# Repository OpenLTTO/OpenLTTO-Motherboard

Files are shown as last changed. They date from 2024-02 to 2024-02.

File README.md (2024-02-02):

# OpenLTTO
The OpenLTTO Project is an attempt to recreate the Lazer Tag Team Ops protocol, and game system, in a completely open-source solution. Eventually our intent, is to expand on the LTTO system, adding new functionality, and features, while maintaining backwards compatibility with this classic Lazer Tag gear.

> This Project wouldn't be possible without all the hard work of Richie Mickan https://github.com/rmick
> His work on recreating the LTTO Protocol, and the development of the Combobulator app are core to the firmware and capabilities of this project.

> Additionally this is built on top of the excellent product developed and released by Hasbro/Tiger Electronics. And the work done by Tag Ferret to release the technical specs, and unlock much of the magic of the protocol, and the inner workings.

We intend to do this via a collection of open-source hardware components that can act as building blocks, to build anything you might require for a Lazer Tag game (Taggers, Hosting Pods, Zone controllers, utilities, etc). And an opensource firmware to operate it all. 

Shield: [][cc-by-nc-sa]

This work is licensed under a
[Creative Commons Attribution-NonCommercial-ShareAlike 4.0 International License][cc-by-nc-sa].

[][cc-by-nc-sa]

[cc-by-nc-sa]: http://creativecommons.org/licenses/by-nc-sa/4.0/
[cc-by-nc-sa-image]: https://licensebuttons.net/l/by-nc-sa/4.0/88x31.png
[cc-by-nc-sa-shield]: https://img.shields.io/badge/License-CC%20BY--NC--SA%204.0-lightgrey.svg

# OpenLTTO Motherboard
The OpenLTTO Motherboard is a simple circuit, which mainly breaks out connectors from an M5Stack CoreS3, which is a packaged microcontroller containing an ESP32-S3 chip. This microcontroller offers a suite of great features making it an ideal centerpiece for the OpenLTTO ecosystem. It is inexpensive, and provides a nice commercial product, with a display, touchscreen, motion sensors, sound output, an SD Card slot, and plenty of internal flash and RAM, along with a powerful dual core 240Mhz processor.

## Hardware Interfaces
The OpenLTTO Motherboard has multiple hardware interfaces that can be used in many ways to construct Lazer Tag gear

### IR Ports
The OpenLTTO Motherboard has 4x IR Ports, which allow interfacing any of our IR Modules. Each port can be individually addressed with independent IR Transmit and Receive functions in order to sense where incoming tags come from, and control where IR packets are sent. Modules can also be daisy chained together on a single port, which makes them function in unison at a single address (all modules include an "IN" and an "OUT" port to allow chaining)

### Switch Ports
The Switch ports allow interfacing buttons or switches to the motherboard, such as user interaction buttons, or trigger/reload switches, etc. These can then be mapped in the configuration screen to various functions.

### RGB Port
The RGB Port is a common pinout for interfacing WS2812 or similar RGB LED chains (often called NeoPixels). These can be chained together, and controlled from the firmware for a number of functions and lighting effects.

### I2C Expansion Port
The I2C Port is reserved for future expansion, it uses the common "Grove" pinout and connector (JST PH 2.0). This will allow adding any other I2C based peripherals in the future.

### Battery Connection
The Battery Connection supports any single parallel cell 3.7V Lithium Polymer, or Lithium Ion batteries (for example you can have a single cell, or you can hook up multiple cells in parallel, but never in series). The M5Stack CoreS3 has a USBC port and can manage battery levels, and charge the battery via USBC.

## OpenLTTO Motherboard Top Side (interface to M5Stack CoreS3)
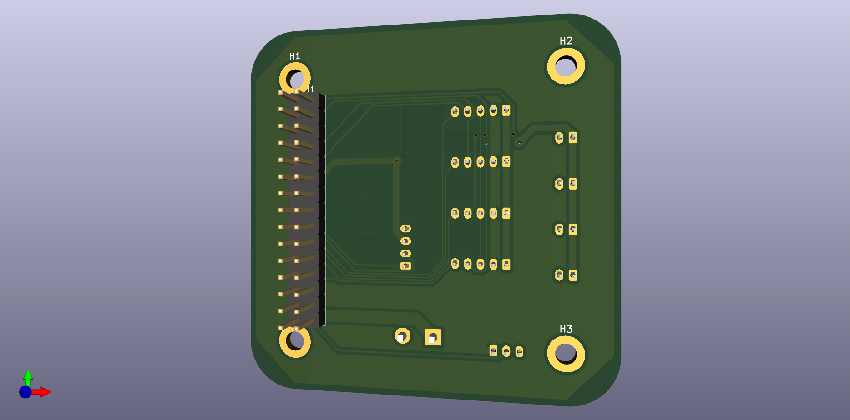
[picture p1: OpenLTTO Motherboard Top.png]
![Image of OpenLTTO Motherboard Top](

## OpenLTTO Motherboard Bottom Side
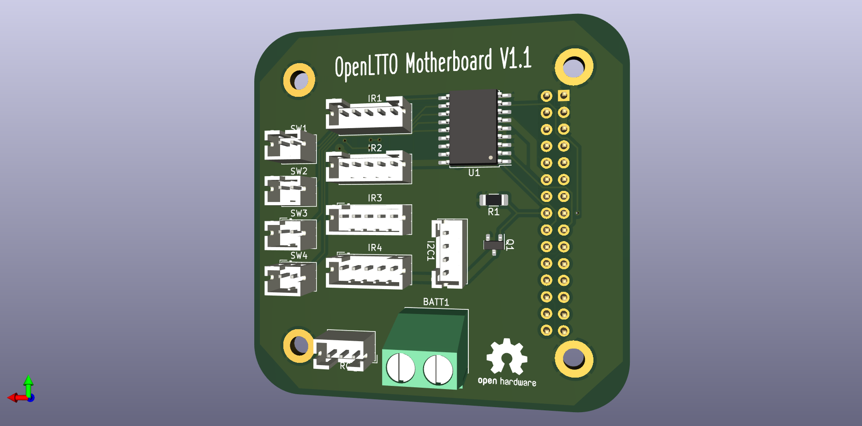
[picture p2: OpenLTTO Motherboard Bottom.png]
Image of OpenLTTO Motherboard Bottom


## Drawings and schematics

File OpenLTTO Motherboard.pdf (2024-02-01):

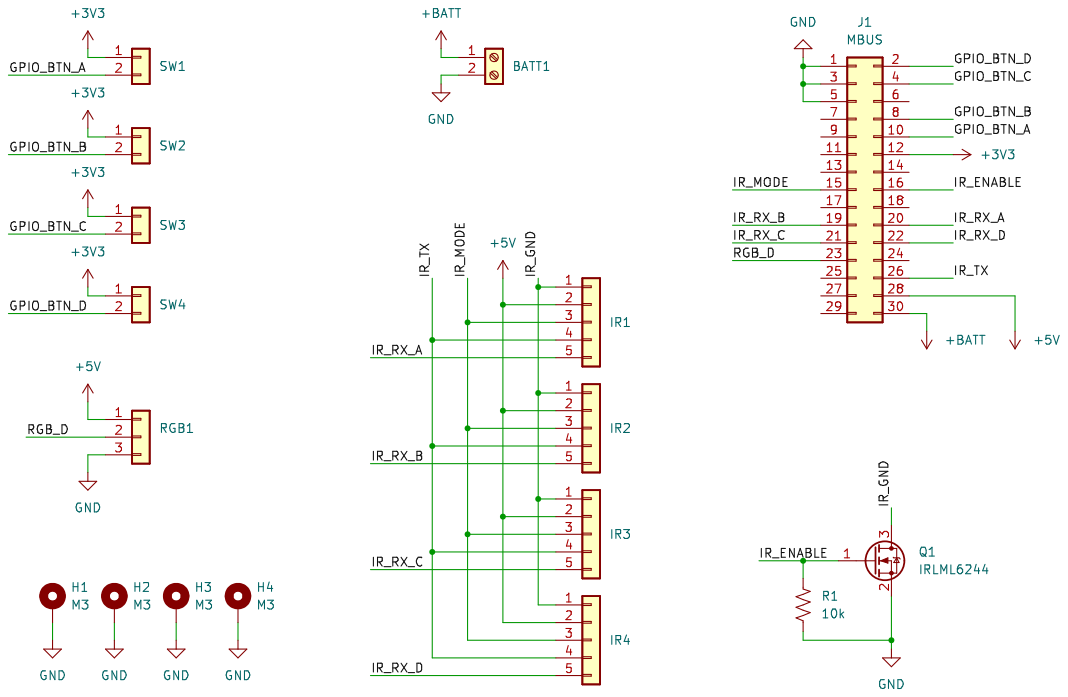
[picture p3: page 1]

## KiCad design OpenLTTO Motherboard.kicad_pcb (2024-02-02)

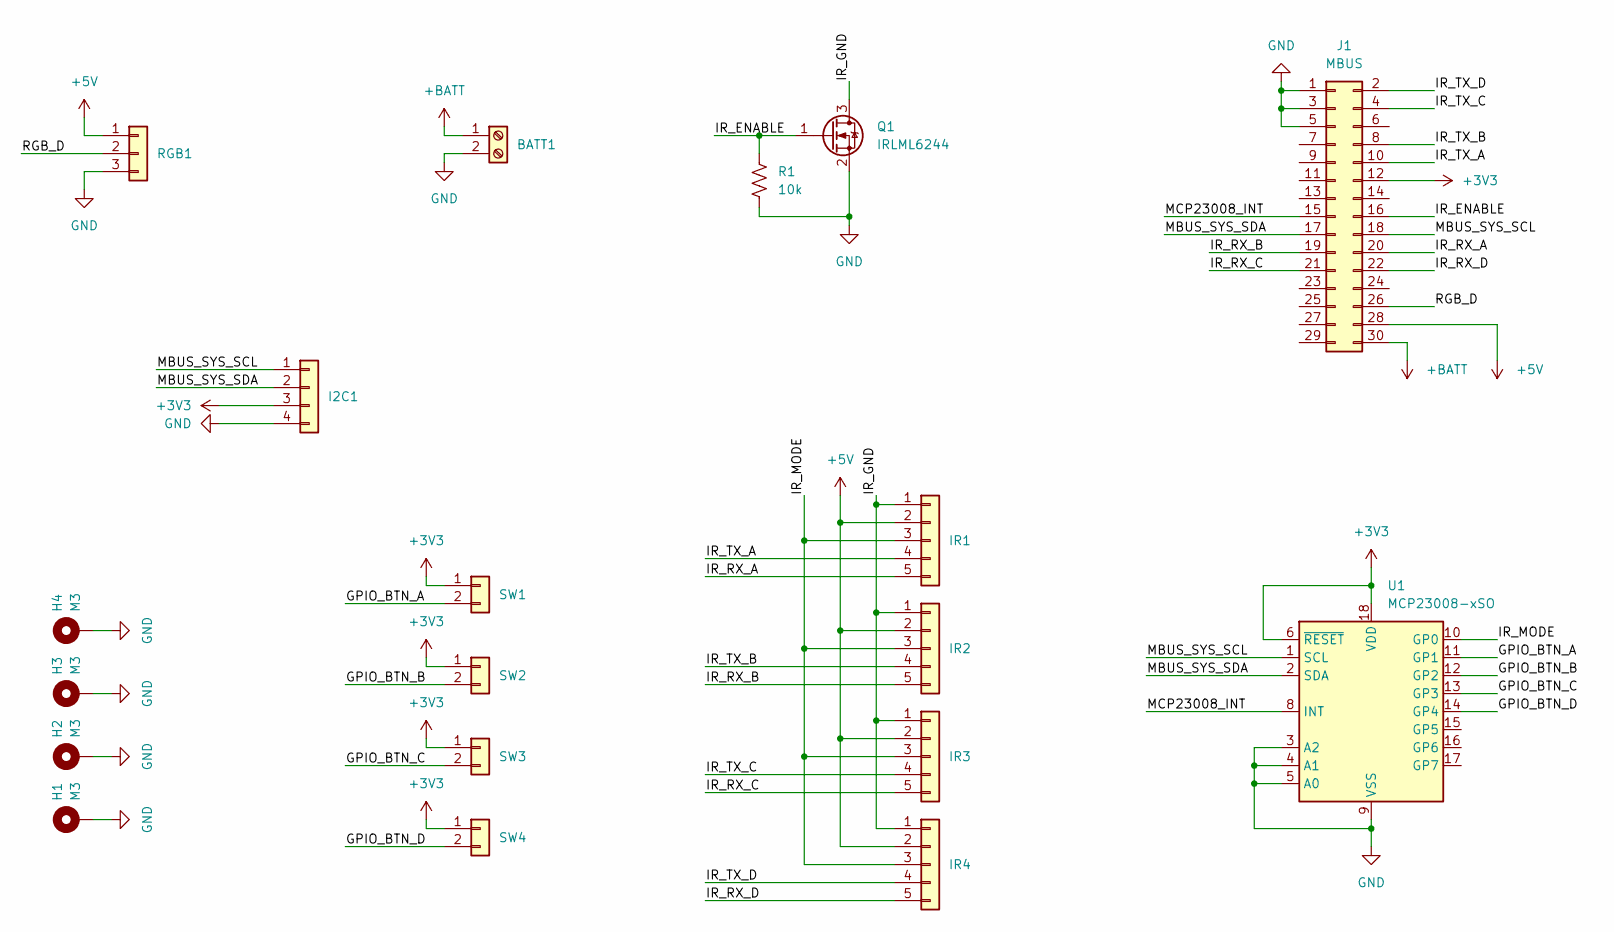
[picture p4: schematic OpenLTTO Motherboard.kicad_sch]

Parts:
BATT1: TerminalBlock_Phoenix_MKDS-1,5-2_1x02_P5.00mm_Horizontal
H1, H2, H3, H4: M3; MountingHole_3.2mm_M3_DIN965_Pad
I2C1: JST_PH_B4B-PH-K_1x04_P2.00mm_Vertical
IR1, IR2, IR3, IR4: JST_PH_B5B-PH-K_1x05_P2.00mm_Vertical
J1: MBUS; PinHeader_2x15_P2.54mm_Vertical
Q1: IRLML6244; SOT-23
R1: 10k; R_1206_3216Metric_Pad1.30x1.75mm_HandSolder
RGB1: JST_PH_B3B-PH-K_1x03_P2.00mm_Vertical
SW1, SW2, SW3, SW4: JST_PH_B2B-PH-K_1x02_P2.00mm_Vertical
U1: MCP23008-xSO; SOIC-18W_7.5x11.6mm_P1.27mm

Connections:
+3V3: I2C1.3, J1.12, SW1.1, SW2.1, SW3.1, SW4.1, U1.6 (~RESET), U1.18 (VDD)
+5V: IR1.2, IR2.2, IR3.2, IR4.2, J1.28, RGB1.1
+BATT: BATT1.1, J1.30
/GPIO_BTN_A: SW1.2, U1.11 (GP1)
/GPIO_BTN_B: SW2.2, U1.12 (GP2)
/GPIO_BTN_C: SW3.2, U1.13 (GP3)
/GPIO_BTN_D: SW4.2, U1.14 (GP4)
/IR_ENABLE: J1.16, Q1.1 (G), R1.1
/IR_GND: IR1.1, IR2.1, IR3.1, IR4.1, Q1.3 (D)
/IR_MODE: IR1.3, IR2.3, IR3.3, IR4.3, U1.10 (GP0)
/IR_RX_A: IR1.5, J1.20
/IR_RX_B: IR2.5, J1.19
/IR_RX_C: IR3.5, J1.21
/IR_RX_D: IR4.5, J1.22
/IR_TX_A: IR1.4, J1.10
/IR_TX_B: IR2.4, J1.8
/IR_TX_C: IR3.4, J1.4
/IR_TX_D: IR4.4, J1.2
/MBUS_SYS_SCL: I2C1.1, J1.18, U1.1 (SCL)
/MBUS_SYS_SDA: I2C1.2, J1.17, U1.2 (SDA)
/MCP23008_INT: J1.15, U1.8 (INT)
/RGB_D: J1.26, RGB1.2
GND: BATT1.2, H1.1, H2.1, H3.1, H4.1, I2C1.4, J1.1, J1.3, J1.5, Q1.2 (S), R1.2, RGB1.3, U1.3 (A2), U1.4 (A1), U1.5 (A0), U1.9 (VSS)

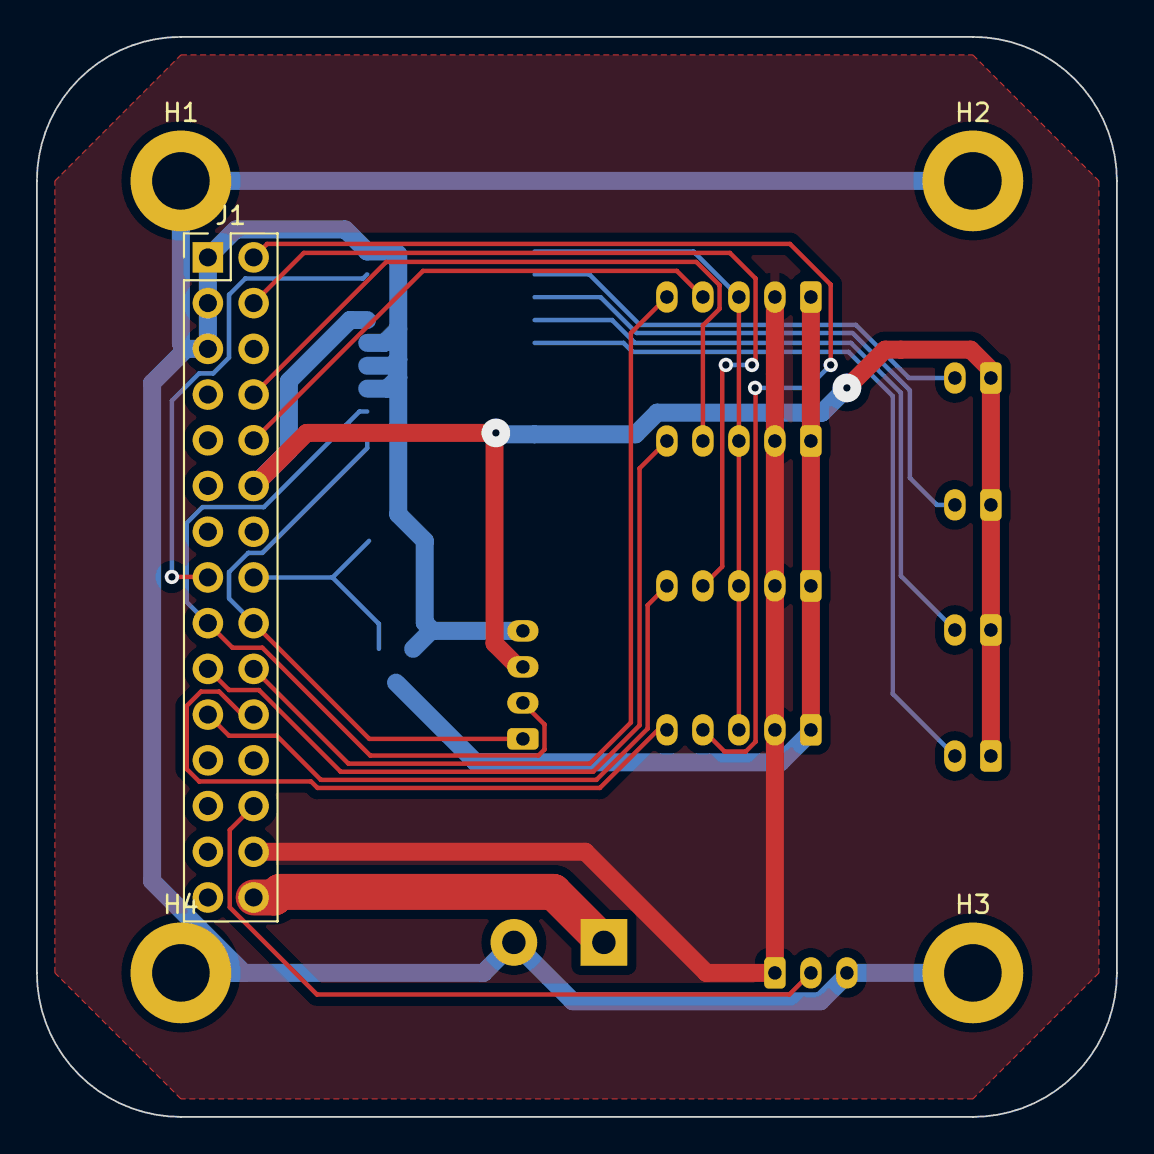
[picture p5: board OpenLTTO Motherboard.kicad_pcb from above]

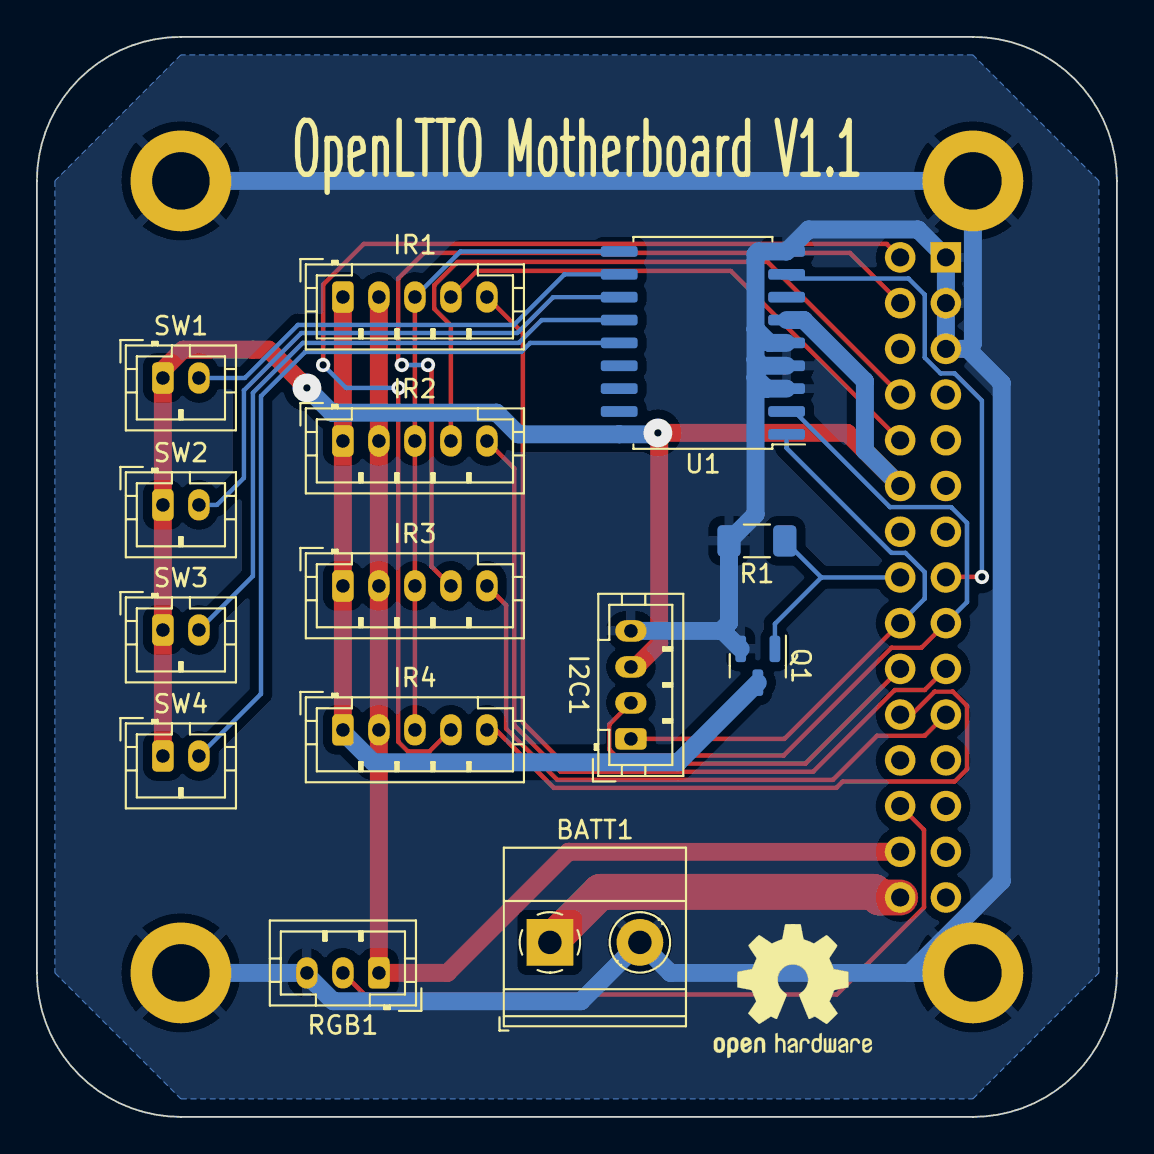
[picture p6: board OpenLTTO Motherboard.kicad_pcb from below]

Board: 2 copper layers, 60.0 x 60.0 mm, 19 parts (14 on the bottom side), 23 nets.

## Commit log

2024-02-01 Updated schematic metadata, and added PCB renders, and schematic PDF
    [OpenLTTO Motherboard.kicad_sch]
2024-02-02 Updated Schematic to v1.1, added GPIO breakout and changed IR ports to all be independent. Also added I2C port, and added license, and updated readme
    [OpenLTTO Motherboard.kicad_pcb, OpenLTTO Motherboard.kicad_sch]

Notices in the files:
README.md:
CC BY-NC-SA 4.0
